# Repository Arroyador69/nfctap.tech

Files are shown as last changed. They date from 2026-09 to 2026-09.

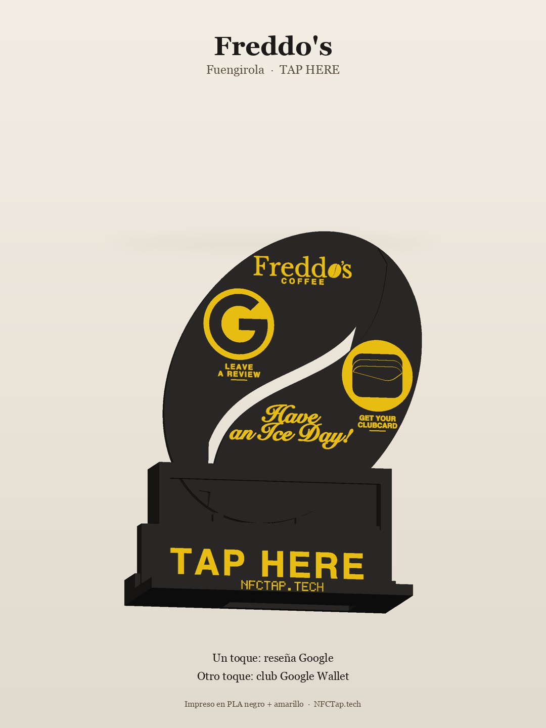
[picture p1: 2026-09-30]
disenos/stl/freddos-fuengirola/opcion-tap/whatsapp/Freddos-NFC-propuesta.jpg

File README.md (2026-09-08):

# NFCTap.tech — tarjetas NFC de reseñas Google

Marca: **nfctap.tech** (canónico). `nfctab.tech` redirige aquí hasta que deje de renovarse. Web en `web/` (Next.js, Vercel). App de programación NFC en `nfctap-config/` (**NFCTap Config**). Diseños 3D en `disenos/`.

```bash
cd web && npm install && npm run dev
```

- Tienda: http://localhost:3000
- Personalizar + pagar: http://localhost:3000/personalizar
- Dashboard: http://localhost:3000/dashboard (clave `nfctab` hasta que pongas `DASHBOARD_PASSWORD`)

Deploy Vercel: root directory = `web`. Polar se conecta después (env en `web/.env.example`).

Cada push a GitHub lanza **Actions → CI** (lint + build de `web/`).

### De un pedido al STL

1. Cliente (o tú en `/dashboard/nuevo`) diseña y guarda.
2. En el pedido: **Descargar ZIP para Orca** (STL + colores + pausa NFC + URL).
3. Orca-Flashforge → importar 01–05 → ensamblar → color por pieza → pausa → imprimir.
4. Local, si quieres regenerar: `python3 disenos/generar_tarjetas.py --pedido pedido.json`

En Vercel, crea un Blob Store y pon `BLOB_READ_WRITE_TOKEN` para que los pedidos no se pierdan.

---

# Impresora Flashforge AD5X

Proyecto listo para cuando llegue la impresora: diseños STL, cómo meter la tira NFC a media impresión y cómo programarla para que el móvil abra la reseña de Google.

---

## Respuesta rápida

**¿Puedes poner cualquier color?** Sí. Compras el filamento del color que quieras (hay cientos: negro, blanco, oro, rojo marca del cliente, silk, mate…). La AD5X no limita el color. Lo que limita es **cuántos colores caben a la vez**: el IFS lleva **4 bobinas**. En una sola tarjeta puedes combinar hasta 4 colores. Entre un pedido y otro cambias bobinas y usas los que quieras.

**¿Hay repos y plantillas?** Sí. Abajo tienes los que valen y, además, **ya tienes las primeras tarjetas generadas en este proyecto** (no dependes de Cults de pago).

**Flujo completo:** diseñar → rebanar en Orca-Flashforge → pausar en la capa del hueco → meter la pegatina NFC Ø25 mm → terminar impresión → escribir la URL de Google con NFC Tools o NFCTap Config.

---

## 1. Tu impresora: Flashforge Adventurer 5X (AD5X)

Comprada el 3 sep 2026, [Amazon B0DMWCWZXL](https://www.amazon.es/dp/B0DMWCWZXL), ~349 €. Nº1 en impresoras 3D en Amazon.es.

| Dato | Valor real |
| --- | --- |
| Volumen | 220 × 220 × 220 mm |
| Velocidad | hasta 600 mm/s (impresión típica ~300 mm/s) |
| Aceleración | 20 000 mm/s² |
| Estructura | CoreXY metálica |
| Boquilla | 0,4 mm de serie (0,25 / 0,6 / 0,8 opcionales), hasta 300 °C |
| Cama | PEI magnética, hasta 110 °C |
| Colores a la vez | **4** con IFS (Intelligent Filament System) |
| Recarga auto | sí, hasta 4 kg / 4 canales del mismo color |
| Materiales | PLA, HS PLA, mate, silk, PETG, ASA, TPU, PLA-CF, PETG-CF |
| Software | **Orca-Flashforge** (recomendado) o Orca Slicer |
| Conexión | Wi-Fi, USB, Ethernet |
| App / granja | Flash Maker |

Para estas tarjetas usa **PLA mate** (o HS PLA). Queda más “producto” y no brilla de forma barata. **No uses filamento con fibra de carbono ni metal** cerca del NFC: atenúa o mata la señal.

Docs oficiales útiles:

- [Impresión multicolor AD5X](https://www.flashforge.com/a/docs/ad5x/multi-color-printing)
- [Enviar a imprimir desde Orca-Flashforge](https://www.flashforge.com/a/docs/ad5x/print-via-orca-flashforge)
- [Producto AD5X](https://www.flashforge.com/products/flashforge-ad5x-3d-printer)

En la cama de 220 mm caben **2 atriles genéricos** a tamaño real. Una sola pausa (capa 24) sirve para las dos pegatinas.

---

## 2. Cómo se diseñan (y qué hay ya hecho)

Una tarjeta de reseña no es un solo bloque. Son **piezas de color** + un **hueco interno** para el NFC:

```
   [estrellas oro]  [texto blanco]  [icono]
  -----------------------------------------
 |              CUERPO (negro/color marca)  |
 |           ┌─────────────────┐            |
 |           │  NFC Ø25 mm     │  ← hueco   |
 |           └─────────────────┘            |
  -----------------------------------------
```

### Lo que ya tienes en esta carpeta

```
disenos/
  generar_generica.py              ← atril 15 € (G + estrellas), 3 colorways + placa ×2
  generar_tarjetas.py              ← geometría + cartera / pedidos a medida
  stl/
    generica-negra-amarillo/       ← la de 15 € que más se imprime
    generica-blanca-negra/
    generica-negra-roja/
    opciones/v4-flotante/          ← la genérica: estrellas + G + TAP
    freddos-fuengirola/            ← encargo cliente (no serigrafía)
    alberto-cartera/               ← cartera slim, 2 NFC (WA + web)
```

Cada genérica incluye:

| Archivo | Color | Qué es |
| --- | --- | --- |
| `01_cuerpo.stl` | Negro o blanco | Placa + pie + hueco NFC |
| `02_acento.stl` | Amarillo / negro / rojo | Estrellas + G + TAP + NFCTAP.TECH |
| `01_cuerpo_a.stl` + `01_cuerpo_b.stl` | igual | Dos piezas sueltas (no pegadas) |
| `02_acento_a.stl` + `02_acento_b.stl` | igual | Acento de cada una, mismo sitio |
| `PAUSA_NFC.txt` | — | Capa 24 (4,80 mm) |

**Prueba de impresión (Google review):** Flash Studio → Importar `01_cuerpo.stl` + `02_acento.stl` de `generica-negra-amarillo/` (una). Para dos: `*_a` y `*_b` (cuatro STL, dos grupos). **Agrupar, no Reparar.** Pausa **capa 24**. Pegatina Timeskey Ø25 hundida, adhesivo a la cama.

### Regenerar genéricas

```bash
python3 disenos/generar_generica.py
```

### Personalizar un cliente (cartera / pedido plano)

```bash
python3 disenos/generar_tarjetas.py \
  --nombre "bar-pepe" \
  --linea1 "BAR PEPE" \
  --linea2 "RESEÑA" \
  --nfc moneda_25
```

Stock NFC (los primeros 50): [Timeskey NTAG215 Ø25 mm](https://www.amazon.es/dp/B08LD99GZT). El hueco por defecto es `moneda_25` (Ø 28 + 0,4 mm de holgura → **~Ø 28,4 × 0,8 mm**), para meterla a mano sin que roce.

| Preset | Hueco | Para qué |
| --- | --- | --- |
| **`moneda_25`** | Ø 28 × 0,8 mm | **Pegatinas Timeskey Ø25 mm (el stock)** |
| `moneda_30` | Ø 31,5 × 1,0 mm | Monedas grandes |
| `tira_45x15` | 47 × 17 × 0,8 mm | Tiras adhesivas (si compras otras) |
| `tira_40x20` | 42 × 22 × 0,8 mm | Tiras más anchas |
| `tira_35x15` | 37 × 17 × 0,8 mm | Tiras cortas |

Si una pegatina concreta roza, sube `d` en `PRESETS_NFC` de `generar_tarjetas.py`. El hueco debe quedar **~1,5 mm más grande por lado** que el chip.

### En Orca-Flashforge (cuando llegue la máquina)

1. Instala [Orca-Flashforge](https://www.flashforge.com) y elige impresora **AD5X**.
2. Añade hasta 4 filamentos en la barra izquierda (IFS = máx. 4).
3. Importa `01_cuerpo.stl`, `02_estrellas.stl`, `03_texto.stl`, `04_icono.stl`.
4. Si no coinciden, selecciónalos todos → clic derecho → **Ensamblar** (o alinea origen).
5. En el panel Objetos, asigna un color/filamento a cada pieza.
6. Opcional: **Añadir texto** para el nombre del negocio (relieve 0,4 mm).
7. Rebana. En **Vista previa**, slider derecho → capa de `PAUSA_NFC.txt` → clic derecho → **Añadir pausa**.
8. Activa **Enable IFS**, mapea canales (negro→canal X, etc.) y envía.

Ajustes que funcionan bien en tarjetas:

- Capa 0,20 mm (si quieres más detalle en texto: 0,16 mm y recalcula la capa de pausa)
- 3 perímetros, relleno 15–20 % gyroid
- Primera capa lenta, cama PEI limpia
- Generador de paredes **Arachne** para el texto
- PLA ~210/60 °C (sigue el carrete)

---

## 3. Repos, plantillas y sitios (investigado)

No hay un “GitHub oficial de tarjetas Google”. El nicho está en modelos 3D + apps NFC. Esto es lo que sí existe y sirve:

### Código / generadores (gratis)

| Recurso | Para qué |
| --- | --- |
| [nfc-keychain-generator-blender-addon](https://github.com/Clonephaze/nfc-keychain-generator-blender-addon) | Addon de Blender: tarjetas, llaveros, hueco NFC, SVG, QR |
| [Dog tag paramétrico RFID (Printables + OpenSCAD)](https://www.printables.com/model/438828-universal-parametric-rfid-compatible-dog-tag-gener) | Generador OpenSCAD con hueco RFID/NFC |
| **Este repo (`generar_tarjetas.py` + `.scad`)** | Plantilla propia, lista para AD5X y tus tiras |

### Modelos listos para descargar

| Recurso | Notas |
| --- | --- |
| [MakerWorld — Minimalist Google Review NFC & QR](https://makerworld.com/en/models/1469384-minimalist-google-review-nfc-qr-code) | Soporte de mesa + QR (el QR hay que generarlo tú) |
| [MakerWorld — NFC stand con chip embebido](https://makerworld.com/en/models/2370320-nfc-customizable-stand-embedded-chip) | Pausa ya puesta, chip 25 mm |
| [MakerWorld — QR sign paramétrico + NFC](https://makerworld.com/en/models/2401859-customizable-qr-code-sign-nfc-frame-optional) | Muy configurable |
| [Printables — soporte NFC de mostrador](https://www.printables.com/model/1186851-curved-tabletop-nfc-tag-holder) | Atril, se inserta el tag a media impresión |
| [Cults — Smart NFC Review Card](https://cults3d.com/tr/3d-model/ev/smart-nfc-review-card-boost-your-business) | De pago; 85,6×54×3 mm, pausa en capa 10 |

### Programar el NFC (apps)

- [NFC Tools](https://www.wakdev.com/en/apps/nfc-tools.html) — iOS y Android (la que usarás)
- NFC TagWriter (NXP) — alternativa Android
- [Guía de escritura de tarjetas NFC para reseñas](https://upwardbound.media/resources/nfc-card-programming)

Slicer y pausa: [cómo añadir pausa en OrcaSlicer](https://printago.io/guides/orca-slicer-pause-at-layer) (Orca-Flashforge es el mismo motor).

---

## 4. Meter la pegatina NFC a media impresión

1. La impresora hace el pozo Ø28 y el asiento Ø26 (anillo de acento = mira).
2. **Pausa** en la primera capa que taparía el hueco (genérica: **4,80 mm / capa 24**).
3. Colocas la pegatina Timeskey **Ø25 mm hundida y centrada**, adhesivo hacia la cama, sin que sobresalga.
4. Reanudas. La impresora sella el NFC dentro. Queda invisible y protegido. Si sobresale, no reanudes (montañita).

Consejos que evitan fallos:

- El nozzle está caliente: no toques la cama; usa pinzas si hace falta.
- Estas pegatinas son finas (~0,2 mm). El pozo tiene 1,6 mm de alto: caben holgadas.
- No las pongas arrugadas: el cabezal las puede arrancar.
- Programa el NFC **después** (atraviesa el PLA sin problema) o **antes** si quieres probar el chip. Después es más cómodo.
- iPhone lee NFC de serie; Android también (NFC activado).
- No van sobre metal. No las pases a solo lectura hasta comprobar el enlace.

---

## 5. Programar el NFC para Google Reviews

Necesitas el **enlace directo a escribir reseña**, no el Maps genérico.

### Conseguir el enlace (elige uno)

**A. Desde el perfil de empresa (más fácil)**  
[Google Business Profile](https://business.google.com) → el negocio → **Pedir reseñas** / Ask for reviews → copiar el enlace corto:

`https://g.page/r/XXXXXXXX/review`

**B. Con Place ID**  
1. Abre el [Place ID Finder de Google](https://developers.google.com/maps/documentation/javascript/examples/places-placeid-finder).  
2. Busca el negocio, copia el `place_id` (empieza por `ChIJ…`).  
3. Monta:

`https://search.google.com/local/writereview?placeid=AQUI_EL_PLACE_ID`

Ese enlace abre **directamente el formulario de reseña**.

### Escribirlo en el chip

1. Instala **NFC Tools** en el móvil.
2. Write / Escribir → Add a record → **URL / URI**.
3. Pega el enlace de reseña.
4. Write → acerca el móvil a la tarjeta (por la cara, 1–2 cm).
5. Prueba con **otro** móvil: debe abrir Google y la reseña, sin app extra.
6. Cuando esté bien, en NFC Tools puedes **bloquear** el tag (write-protect) para que el cliente no lo pisen. Bloquea solo al entregar.

Chips que funcionan (NTAG de NXP, los que entiende iPhone y Android):

| Chip | Memoria | Recomendado |
| --- | --- | --- |
| NTAG213 | ~180 B | Vale para una URL corta |
| **NTAG215** | ~504 B | **El que debes comprar** |
| NTAG216 | ~888 B | Sobra para esto |

Las Timeskey B08LD99GZT son **NTAG215**. Si al escribir falla por “poca memoria”, acorta la URL (usa el `g.page`).

---

## 6. Lista de la compra para el día 1

Ya tienes la impresora. Falta esto:

| Qué | Para qué | Nota |
| --- | --- | --- |
| PLA mate negro 1 kg | Cuerpo | El 80 % de los pedidos |
| PLA blanco 1 kg | Texto / icono | Contraste |
| PLA oro / amarillo silk | Estrellas | Aspecto “5 estrellas” |
| 1 color extra (rojo, azul, verde) | Marca del cliente | El 4º canal del IFS |
| Pegatinas NFC **NTAG215 Ø25 mm** | El chip | [Timeskey B08LD99GZT](https://www.amazon.es/dp/B08LD99GZT); si compras más, mismas Ø25 |
| Alcohol isopropílico | Limpiar PEI | Primera capa limpia |
| Orca-Flashforge | Slicer | Gratis, web Flashforge |
| NFC Tools | Programar | Gratis en App Store / Play |

Opcional más adelante: PLA de colores de marca (corporativos), PETG si van a terraza al sol, más AD5X cuando escales (la propia Flashforge las vende como granja).

---

## 7. Coste y producto (para el negocio)

Números de la genérica 15 € (ver `COSTE.txt` en cada carpeta):

- PLA ~47 g → **~1,04 €**
- NFC NTAG215 Ø25 → **~0,45 €**
- Luz + fallos → **~0,47 €**
- Coste ~**1,96 €**/ud · venta **15 €** · margen ~13 €
- En cama caben **2** a tamaño real (`*_a.stl` + `*_b.stl`, sueltas)

No uses el **logotipo oficial de Google** (la G de 4 colores) en producto a la venta sin permiso de marca. “Reseña en Google”, estrellas y un icono genérico es lo correcto y es lo que generan estos STL.

---

## 8. Plan de las próximas semanas

1. **Hoy:** imprimir `generica-negra-amarillo` (o `*_a` + `*_b` para dos sueltas). Pausa capa 24. G + estrellas.
2. **Stock:** negra+amarillo, blanca+negra, negra+roja. Misma geometría.
3. **Pedido web:** `/personalizar?kind=generica` → ZIP / `generar_generica.py`.
4. **Personalizada 30 €:** mismo atril, logo + textos.

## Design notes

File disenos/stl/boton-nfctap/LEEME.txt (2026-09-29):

Botón NFCTap — marca (NFC / Tap / .Tech)
========================================

Mismo tamaño que la lista nevera: Ø38 × 2.0 mm.
Cara: NFC arriba, Tap, .Tech (con el punto). Aro amarillo.
NFC Timeskey Ø25 en el centro. Pausa a mitad.

  01_cuerpo.stl   negro
  02_acento.stl   blanco  (letras + mira NFC)
  03_aro.stl      amarillo (aro exterior)

Agrupar las 3. NO Reparar.

Uso
---
Pegar en el cajón de filamento / taller. Programar el chip
con NFCTap Config → URL https://nfctap.tech/taller/casa
(misma clave que la lista nevera; solo Wi‑Fi de casa).

Imprime
-------
Pausa OBLIGATORIA capa 7 (1.40 mm). Ver PAUSA_NFC.txt.
Pozo Ø28, asiento Ø26, pegatina Ø25.
REVERSO en la cama. Pegar ese lado (cinta 3M).

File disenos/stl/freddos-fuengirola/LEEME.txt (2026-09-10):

Freddo's Fuengirola — grano NFC + cuna-letras
=============================================

Que es
------
1. GRANO rugby inclinado, S HUECA como el logo (se ve el aire).
   Los lóbulos son UNA pieza: carne en las puntas + enlace oculto en el nido.
   Disco amarillo + TAP negro. Dos NFC Ø25. Abajo: tetones.
2. CUNA = placa negra + Freddo's ENTERO en amarillo (04). El nido va
   8 mm POR ENCIMA del wordmark. El pie delantero queda BAJO las letras,
   no las tapa. Grano de arriba:
   ranura 8,8 mm, labio 8,5 mm, nido 34 mm, agujeros de los tetones.
3. Firma en el pie, debajo de Freddo's: NFCTAP.TECH

Montaje
-------
        [        GRANO (de lado)        ]
        [   tetones → agujeros del nido ]
        [   ranura en lo alto de Freddo's ]
        [  F r e d d o ' s              ]
        [  NFCTAP.TECH                  ]
        [=========== pie 72 mm =========]

Imprime
-------
ANTES de las 8 h: test-encaje/ (stub + cuna sin letras). Prueba el tap.

GRANO: solo 01 + 02. Agrupar. Pausa capa 24. NO Reparar.
CUNA:  solo 03 + 04. Agrupar. Negro=03, amarillo=04. Sin pausa.
       NO mezclar el grano en la misma cama.
       Coloca la cuna APOYADA EN LA ESPALDA (la cara plana trasera
       en la cama). Amarillo = último, la cara de Freddo's arriba.
       Sin soportes. Si avisa de regiones flotantes, está mal girada.

Al acabar: cuna DE PIE. Grano de canto, de ARRIBA, tetones primero. Clac.
Los agujeros del nido abren HACIA ARRIBA (caen los tetones). De cara al
cliente no se ven: delante hay pared. Si FlashPrint avisa de contornos
con geometría incorrecta, NO imprimas — el STL está mal.

Pie
---
Fondo 72 mm. Hueco de lastre en el pie TRASERO (tuercas M8).
El estante delantero es bajo: no tapa Freddo's.
Se tapa el hueco con cinta 3M. Lastre + el stand pegado.
Sin cinta, un empujón alto vuelca cualquier PLA de 20 cm.

Colores: negro + amarillo. Los dos como PLA.

Medidas (80 % del original, NFC igual)
--------------------------------------
Alto montado sobre mesa: 205 mm
Letras Freddo's (hasta la ranura): 33 mm
Grano suelto: 143 × 161 × 8 mm
Pie: 159 mm de ancho × 72 mm de fondo
Nido 34 mm · ranura 8.8 mm (holgura 0.8) · labio 8.5 mm
Tetones: 3 × Ø5.8 / agujero Ø6.8 × 7 mm
NFC: pozo Ø36 · asiento Ø30 · pegatina Ø25 (no escala)

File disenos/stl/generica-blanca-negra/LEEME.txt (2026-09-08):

Atril genérico NFCTap — reseña Google (15 €)
============================================

Que es
------
Placa + pie integrado. Estrellas flotantes, G y TAP debajo.
NFC DENTRO, justo bajo la G (o el logo en personalizada). Pausa a mitad.
Antes de pausar se imprime un disco de acento en el suelo del pozo:
eso es la mira. La pegatina va ENCIMA de ese círculo.

  01_cuerpo.stl / 02_acento.stl     una pieza (agrupar, no Reparar)
  01_cuerpo_a/b.stl + 02_acento_a/b.stl   dos SUELTAS en la cama

Personalizada (30 €): el MISMO cuerpo. Logo en acento en vez de la G.

Imprime
-------
Agrupar 01 + 02. NO Reparar el modelo.
Capa 0,20 mm, 3 perímetros, gyroid 15 %, Arachne.
Pausa OBLIGATORIA capa 24 (4.80 mm). Ver PAUSA_NFC.txt.
Pozo Ø28, asiento Ø26, pegatina Ø25.
Se imprime con la cara de la placa hacia arriba (el pie sale hacia Z).
Al acabar se pone de pie.

Colores de esta carpeta: cuerpo = blanco, acento = negro.

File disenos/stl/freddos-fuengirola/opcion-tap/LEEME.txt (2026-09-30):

Freddo's Fuengirola — OPCIÓN cuna TAP
=====================================

No sustituye a la cuna Freddo's de la carpeta padre. Es otra cara.

Qué cambia
----------
Misma cuna negra (ranura, nido, pie, tetones, tamaños).
El grano es el de siempre (Freddo's COFFEE, reseña, clubcard).
En la placa, en vez de repetir Freddo's:

        TAP HERE

Solo inglés, un tamaño que llena la cara (sin español). Vale para los dos chips:
  IZQ  G Google → reseña
  DER  Wallet   → clubcard / ticks del café

Imprime
-------
GRANO: 01 + 02 de la carpeta padre (no hace falta reimprimirlo).
CUNA:  03 + 04 DE ESTA carpeta. Agrupar. Negro=03, amarillo=04.
       Espalda plana en la cama. Sin pausa. Sin soportes.

03 es la misma pieza negra que la cuna Freddo's (copia).
04 es nuevo: TAP HERE + NFCTAP.TECH en el pie.

Medidas (igual que la cuna Freddo's)
------------------------------------
Alto montado: 205 mm
Pie: 145 × 72 mm
Nido 34 mm · ranura 8.8 mm · labio 8.5 mm
Cara: TAP HERE 14.0 mm (solo inglés)

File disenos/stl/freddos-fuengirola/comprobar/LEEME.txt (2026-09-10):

NO IMPRIMIR este STL.
Es el grano YA metido en la cuna, para verlo en FlashPrint.
Si se ve el óvalo encajado de canto, tetones en el suelo del nido, OK.
Lee ENCAJE.txt (mismas cifras del grano y de la cuna).
Para fabricar: 01+02 (grano) y 03+04 (cuna), en dos camas.

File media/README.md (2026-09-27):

# NFCTap · media

Reels solo con **tus grabaciones**. Carrusel solo con **tus fotos**. Subtítulos amarillos. Voces Azure España (Ximena / Tristan).

Cada Reel: **pieza acabada** (hook) → **proceso de impresión** (cuerpo) → **nfctap.tech en uso** (cierre). El cierre dice «Lo podrás encontrar en la web. Envíos a toda España.» con subtítulos amarillos.

## Dónde pegar el material

```
media/assets/bank/resultado/   1 MOV nuevo de pieza acabada → hook
media/assets/bank/proceso/     2 MOV nuevos de impresión / NFC / TAP → cuerpo
media/assets/bank/web/         1 MOV LARGO de nfctap.tech → cierre (trozos distintos)
media/assets/bank/imagenes/    3 fotos JPG/PNG → único carrusel del pack
```

Cualquier MOV/MP4 vale para los Reels. El sistema los deja a 1080×1920 sin recortar.

El cierre de la web **no** corta siempre el mismo segundo: recorre el vídeo largo
a trozos. En la suma de Reels se ve casi entero.

Para el carrusel: al menos 3 fotos. Si pones exactamente 3, salen en orden de nombre (`01.jpg`, `02.jpg`, `03.jpg`). Si el iPhone guarda HEIC, exporta a JPG.

## Pack del día

Dos Reels (voz de mujer + voz de hombre) + **un** carrusel de 3 fotos + stories.

Los dos Reels **no abren con el mismo clip**. Si el de María usa `IMG_0562`, el de Andrés usa otro de `resultado/`.

```bash
cd media
source .venv/bin/activate
python -m nfctap_media doctor
python -m nfctap_media day
python -m nfctap_media open
```

Aún no publica solo. Polar después.

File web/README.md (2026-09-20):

# NFCTap.tech — web

Tienda + personalizador + dashboard de pedidos. Next.js 16, lista para Vercel.

## Local

```bash
cd web
cp .env.example .env.local
npm install
npm run dev
```

- Tienda: http://localhost:3000
- Personalizar: http://localhost:3000/personalizar
- Dashboard: http://localhost:3000/dashboard · clave por defecto `nfctab`

## Precios (no son 2×1 con cupón)

| Producto | Polar | Precio |
|---|---|---|
| Google / WhatsApp / Instagram × 1 | `POLAR_PRODUCT_GENERIC_1` | 20 € |
| Pack × 2 (también una de cada) | `POLAR_PRODUCT_GENERIC_2` | 35 € (no 40 €) |
| Con logo × 1 | `POLAR_PRODUCT_CUSTOM_1` | 30 € |
| Con logo × 2 | `POLAR_PRODUCT_CUSTOM_2` | 55 € (no 60 €) |
| TAP Wi‑Fi pared × 1+ | `POLAR_PRODUCT_WIFI_1` | 15 € cada una |

La pieza única (70 €) no se vende en Polar: se cierra por email.

En el checkout Polar cobra **producto + envío** (ad-hoc). Península gratis desde 45 € de producto.

## Polar

En [polar.sh](https://polar.sh) (organización NFCTap, **producción**, no sandbox):

1. Settings → Organization Access Token con `products:write`, `checkouts:write` y `checkouts:read`.
2. Settings → Webhooks → endpoint `https://nfctap.tech/api/webhook/polar` (formato Raw). Eventos: `checkout.updated`, `order.created`, `order.paid`. Copia el secret `whsec_…`.
3. Crea los productos (atriles + TAP Wi‑Fi):

```bash
cd web
POLAR_ACCESS_TOKEN=polar_oat_… POLAR_SERVER=production npm run polar:setup
```

El script escribe los IDs en `.env.local`. Pégalos también en Vercel.

4. En Vercel: `POLAR_ACCESS_TOKEN`, `POLAR_WEBHOOK_SECRET`, `POLAR_SERVER=production` y los `POLAR_PRODUCT_*` (incl. `POLAR_PRODUCT_WIFI_1`).

**Bizum** no se activa a mano. Polar lo muestra en el checkout cuando el comprador está en España (EUR, pago único). La web le pasa la IP y el país ES. El cliente confirma en su banco; Polar cobra, envía el recibo y avisa a la web por webhook. No uses Bizum al número de teléfono de la tienda: eso es entre particulares, no hay confirmación automática del pedido.

## Vercel

1. Importa el repo. **Root Directory:** `web`
2. Variables: `DASHBOARD_PASSWORD`, `DASHBOARD_SECRET`
3. Blob: `BLOB_READ_WRITE_TOKEN` (Storage → Blob)
4. Polar (producción): ver arriba

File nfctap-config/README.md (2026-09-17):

# NFCTap Config

App para **programar pegatinas NFC** de NFCTap (`nfctap.tech`). Nombre: **NFCTap Config**. Bundle ID `tech.nfctab.config` (no cambiar: ya está en App Store Connect). «NFC Tap» está pillado en la App Store (ST).

Hoy: **gratis, para ti**. Paywall más adelante.

## Qué graba (NDEF)

Negocio: reseña Google, web, PDF/menú, WhatsApp (prefijo + número + mensaje), app, TripAdvisor, reservas, PayPal.

Redes: Instagram, TikTok, Facebook, Telegram, Maps, YouTube, LinkedIn, X, Spotify.

Contacto: llamada, email, SMS, vCard.

Conexión: **Wi‑Fi con contraseña**. El iPhone **no se une solo** al Wi‑Fi por NFC (Apple no lo permite). Se graba una URL `nfctap.tech/w#…` que abre nombre y clave para copiar, más el registro WSC para que Android a menudo se una solo.

Extra: texto, GPS, URI libre.

El cliente **no instala esta app**. Toca y el sistema abre el enlace.

Se puede programar **cualquier chip NDEF** (NTAG213/215/216, Ultralight…). No: bancarias, bloqueadas, ni MIFARE Classic raras en iPhone.

El chip **no guarda un PDF**: guarda la URL. Las 200 “tareas” de NFC Tools (silencio, brillo…) automatizan **tu** Android y piden su app extra; aquí no, porque el cliente de la barra no las tiene.

## Cómo la ves ya (Expo Go)

```bash
cd nfctap-config
npm start
```

QR con Expo Go: ves pantallas y plantillas. **Expo Go no escribe NFC.**

## Cómo programas de verdad (hoy, Android)

1. Móvil Android con NFC + cable USB.
2. En el Mac:

```bash
cd nfctap-config
npx expo run:android
```

3. Configurar → Reseña Google → pega el enlace de Maps o del perfil de empresa → Buscar enlace. Te da el de reseña.

iPhone: Xcode (Archive para TestFlight). El fallo `impresora: No such file` es el espacio en la carpeta. El plugin `with-quoted-constants-script` y `scripts/bundle-rn-ios.sh` citan las rutas.

```bash
./abrir-xcode.sh
```

Hace falta el capability **NFC Tag Reading**. iPhone 7+.

## Cómo ganan las otras (para el paywall)

| App | Modelo |
| --- | --- |
| NFC Tools | Gratis + Pro ~4 € o IAP. Tareas/automatización en Pro. |
| NFC Tools Pro | App de pago. Perfiles, emular tag, 200 tareas. |
| Smart NFC y clones | Escritura básica gratis, ilimitado / plantillas de pago o suscripción. |

Para NFCTap, el dinero está en **la tarjeta física**. La app puede quedarse gratis para ti y, luego, un Pro (historial en la nube, lotes, varios operarios) si la usáis más gente.

## No hacemos (a propósito)

- Bloquear el chip (write-protect): irreversible en NTAG.
- Clonar pagos / bank cards.
- Automatizar el teléfono del cliente (eso es NFC Tasks, otro rollo).

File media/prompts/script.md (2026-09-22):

Eres el guionista de Reels de NFCTap (nfctap.tech). Hablas a dueños de bares, cafeterías y restaurantes en España.

El vídeo que verán es SIEMPRE material real de Alberto:
- Primeros segundos (hook): la pieza ACABADA en la barra.
- Cuerpo: el PROCESO (impresión, pausa NFC, TAP, logo).
- Cierre: la web nfctap.tech en uso (encargar, 3D, precios). Locutado fijo: «Lo podrás encontrar en la web. Envíos a toda España.»
- El cuerpo no nombra la web ni el envío: eso va solo en el cierre.

Productos (di el que toque, no solo Google):
- Google: se abre la reseña.
- WhatsApp: se abre el chat.
- Instagram: se abre el perfil.
- Pack de dos: también una de cada. 20 € una, 35 € dos. Con logo 30 / 55 €.

Reglas:
- Español de España, tuteo, frases cortas, para decirlas en voz alta.
- 32 a 78 palabras entre hook y cuerpo. 15 a 30 segundos.
- Primer segundo: dolor concreto (se van sin reseña, QR sucio, Maps, anuncios, WhatsApp que no entra, Instagram que no siguen).
- Luego el atril, que lo fabricáis aquí, y el precio solo si está en product.yaml (20 / 35 / 30 / 55 / 70 €).
- El cuerpo termina en el producto. El cierre oral es siempre «Lo podrás encontrar en la web. Envíos a toda España.»
- No locutes la URL larga de /guia/… Eso va en el caption de YouTube/Instagram, no en la voz.
- Si el dolor es reseñas o Maps, el producto es el atril de Google. Si es WhatsApp o Instagram, ese modelo. Si es QR o papel, el atril de barra. Si es Wi‑Fi de pared, la placa de 15 €.
- No inventes partnership con Google, Meta ni WhatsApp. No digas “te lleno el local”.
- No uses nombres de clientes reales. Es una escena, no un testimonio falso.
- No emojis. No hashtags dentro del locutado.
- Si el dolor es Maps o reseñas, habla de Google. Si no, generaliza: WhatsApp, Instagram o Google.

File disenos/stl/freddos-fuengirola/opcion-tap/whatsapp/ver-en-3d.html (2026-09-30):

# Freddo's

Gira con el ratón o el dedo

Tap here: Google review · tap here: Google Wallet · NFCTap.tech

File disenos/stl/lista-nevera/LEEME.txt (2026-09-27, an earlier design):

Botón NFC nevera — lista de la compra
=====================================

Círculo Ø38 × 2.0 mm (fina).
Cara: lista minimalista blanca + aro amarillo en el borde.
NFC Timeskey Ø25 en el centro. Pausa a mitad.

  01_cuerpo.stl   negro
  02_acento.stl   blanco  (lista + mira NFC)
  03_aro.stl      amarillo (aro exterior)

Agrupar las 3. NO Reparar.

Imprime
-------
Pausa OBLIGATORIA capa 7 (1.40 mm). Ver PAUSA_NFC.txt.
Pozo Ø28, asiento Ø26, pegatina Ø25.
REVERSO en la cama. Pegar ese lado a la nevera (cinta 3M).

URL del chip: https://nfctap.tech/lista/casa
Privada: solo Wi‑Fi de casa. Ver NFC.txt.

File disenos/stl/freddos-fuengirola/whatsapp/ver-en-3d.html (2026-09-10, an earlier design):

# Freddo's

Gira con el ratón o el dedo

Un toque reseña Google · otro toque puntos · NFCTap.tech

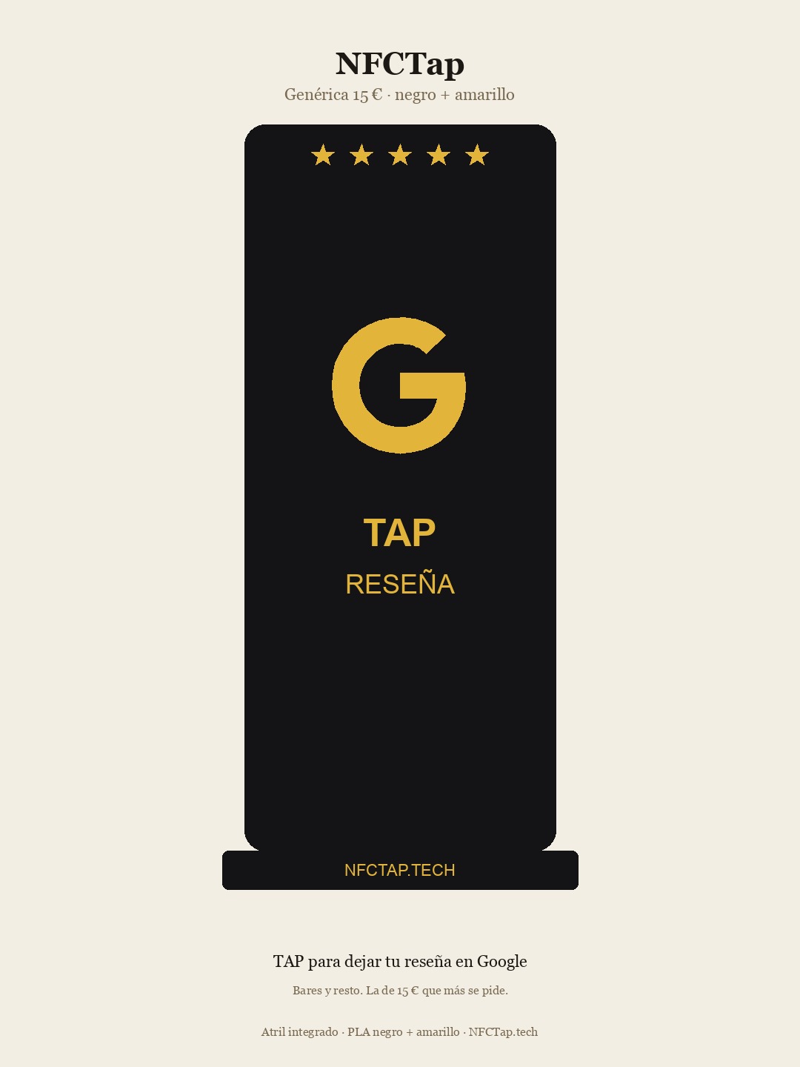
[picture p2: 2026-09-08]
disenos/stl/generica-negra-amarillo/propuesta.jpg

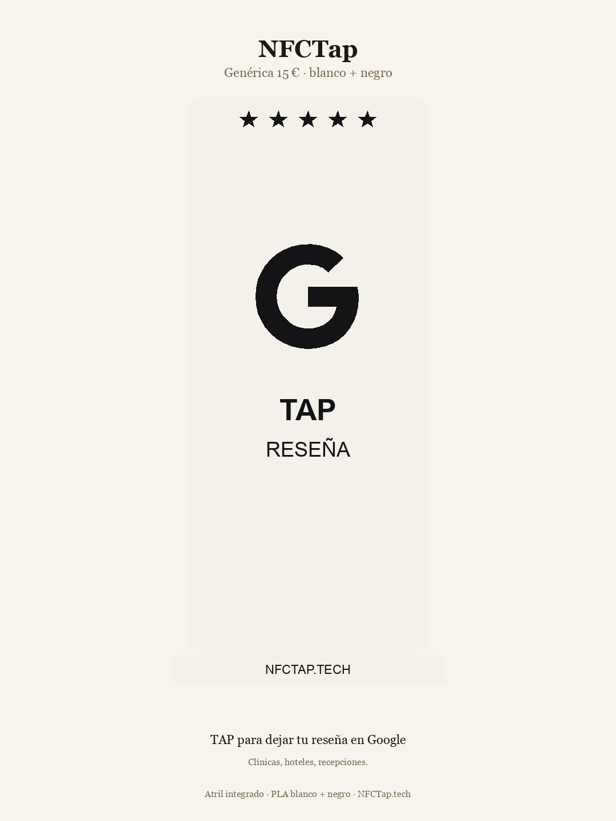
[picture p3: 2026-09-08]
disenos/stl/generica-blanca-negra/vista-previa.png

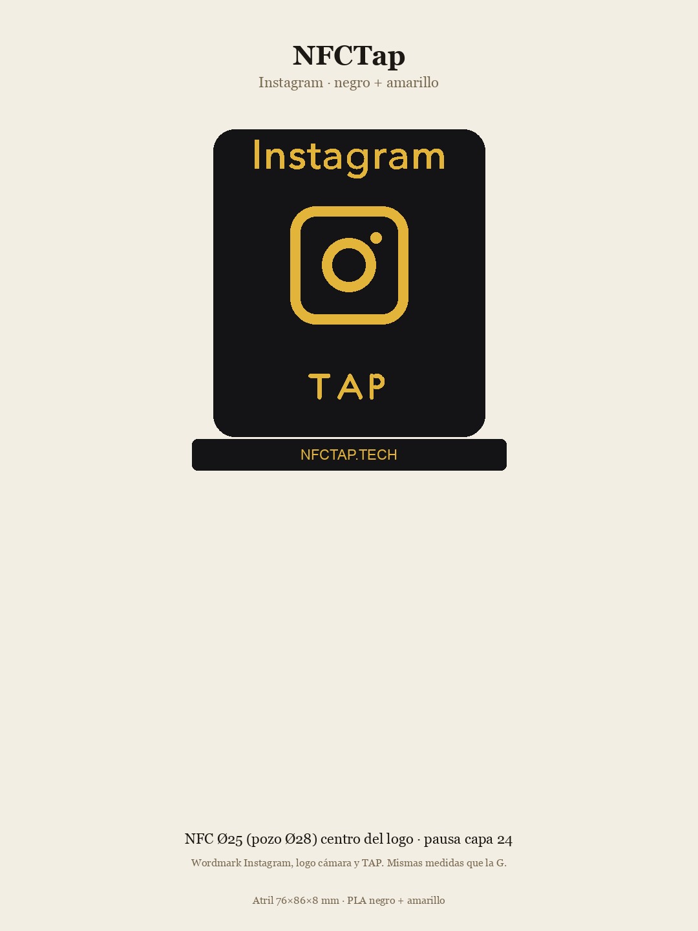
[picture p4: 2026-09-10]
disenos/stl/generica-instagram-negra-amarillo/propuesta.jpg

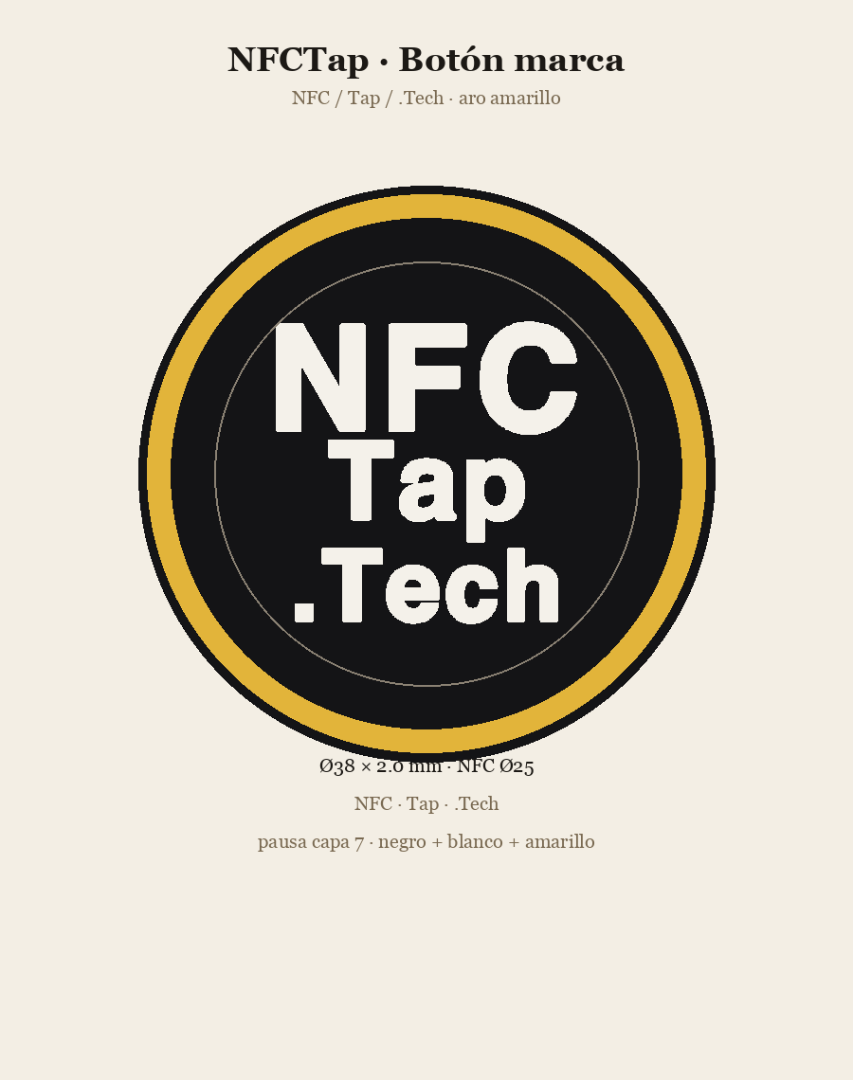
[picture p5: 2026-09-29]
disenos/stl/boton-nfctap/vista-previa.png

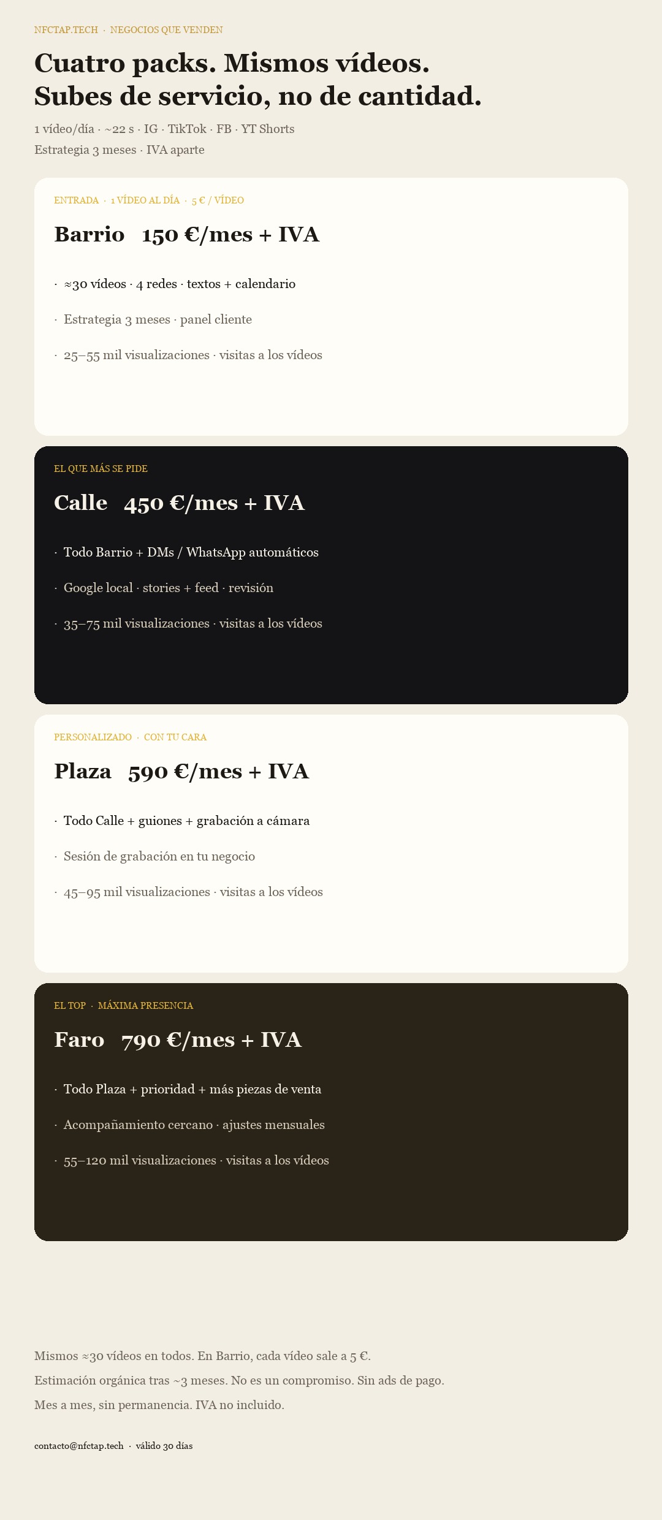
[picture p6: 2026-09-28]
comercial/redes/NFCTap-presupuesto-redes.jpg

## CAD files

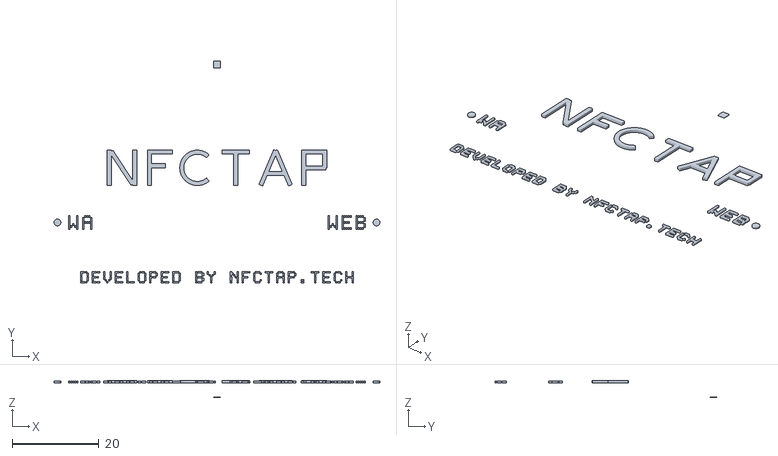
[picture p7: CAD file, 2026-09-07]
disenos/stl/alberto-cartera/02_oro.stl
75.2 x 51.1 x 4.00

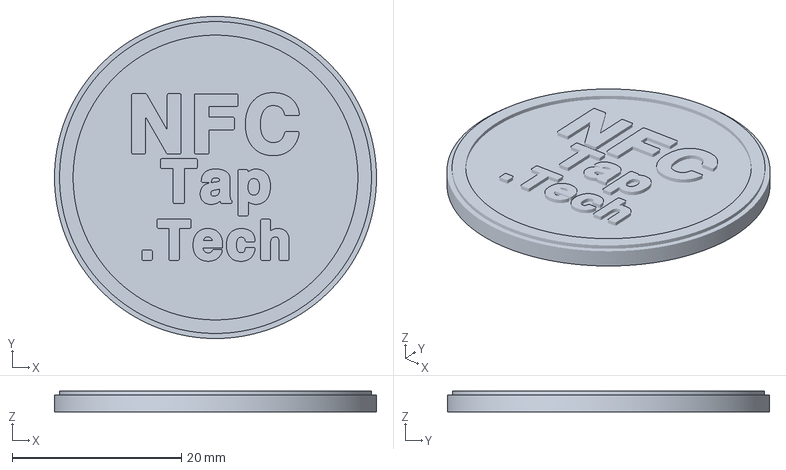
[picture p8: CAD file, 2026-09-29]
disenos/stl/boton-nfctap/boton nfctap.Tech.3mf
38.0 x 38.0 x 2.45 mm

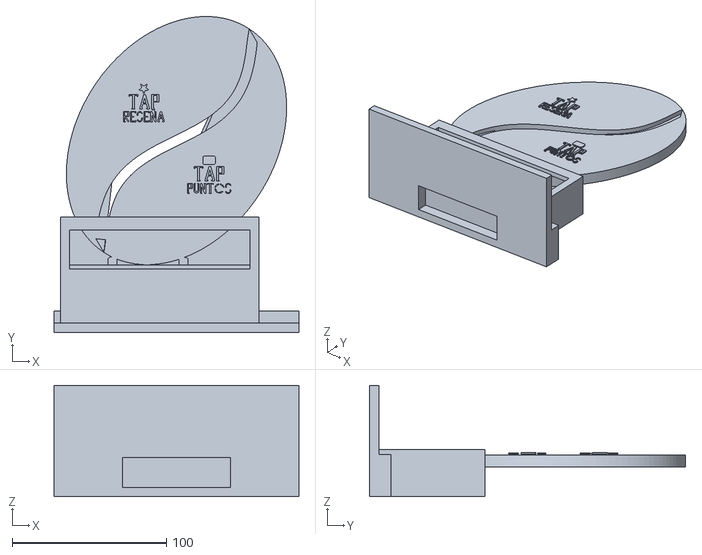
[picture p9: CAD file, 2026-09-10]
disenos/stl/freddos-fuengirola/comprobar/conjunto-NO-IMPRIMIR.stl
158.8 x 204.8 x 72.0

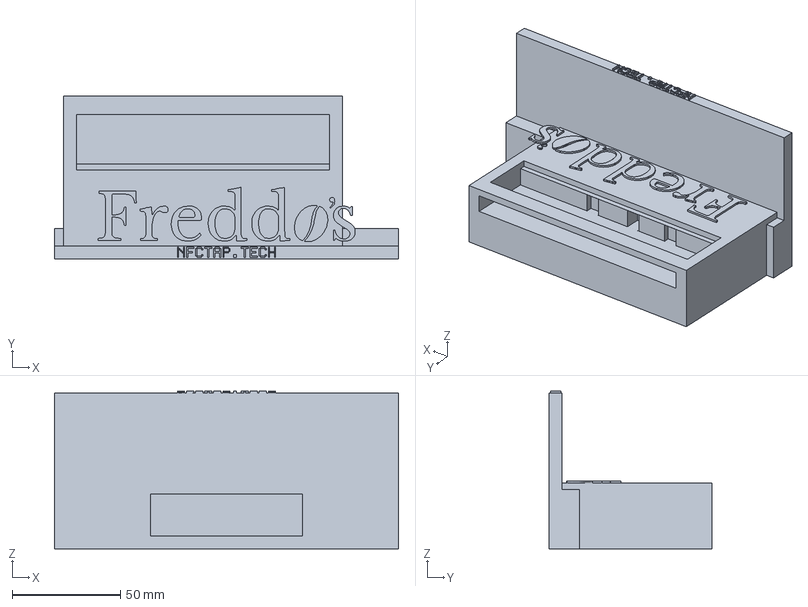
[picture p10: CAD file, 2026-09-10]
disenos/stl/freddos-fuengirola/cuna freddos.3mf
158.8 x 75.0 x 72.8 mm

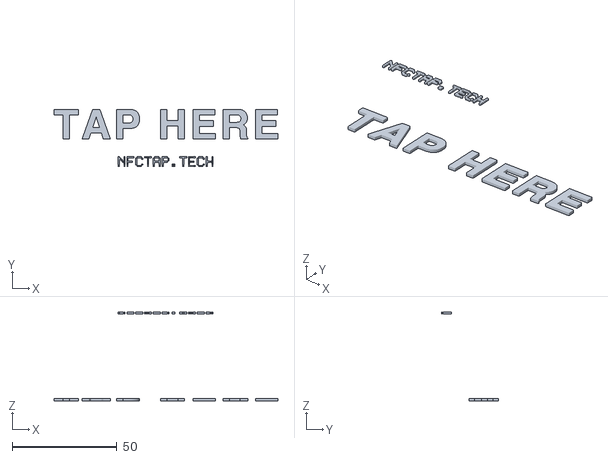
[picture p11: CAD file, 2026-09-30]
disenos/stl/freddos-fuengirola/opcion-tap/04_letras_oro.stl
106.9 x 27.4 x 42.4

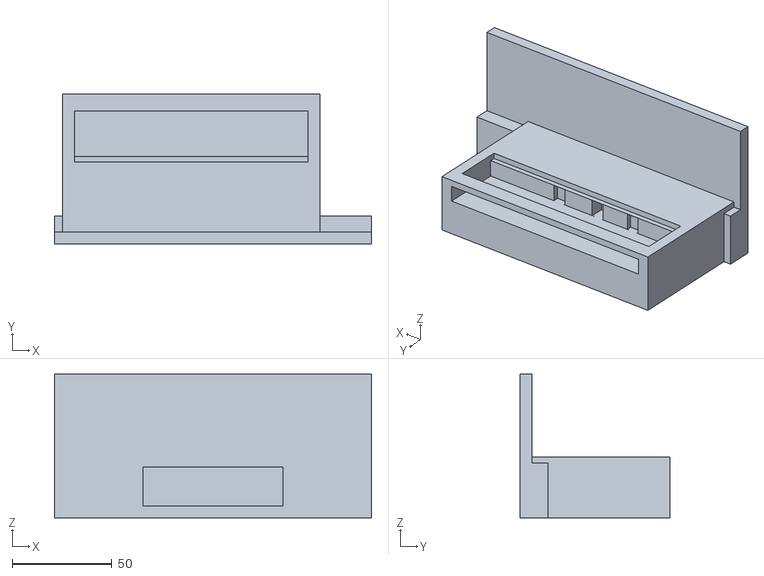
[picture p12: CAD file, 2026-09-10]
disenos/stl/freddos-fuengirola/test-encaje/02_cuna_nido.stl
158.8 x 75.0 x 72.0

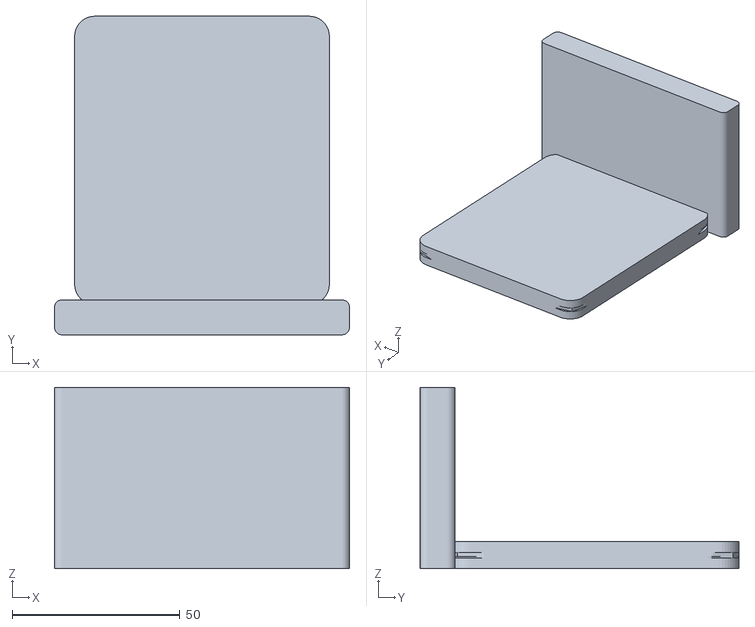
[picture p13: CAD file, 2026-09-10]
disenos/stl/generica-blanca-negra/01_cuerpo_a.stl
88.0 x 95.1 x 54.0

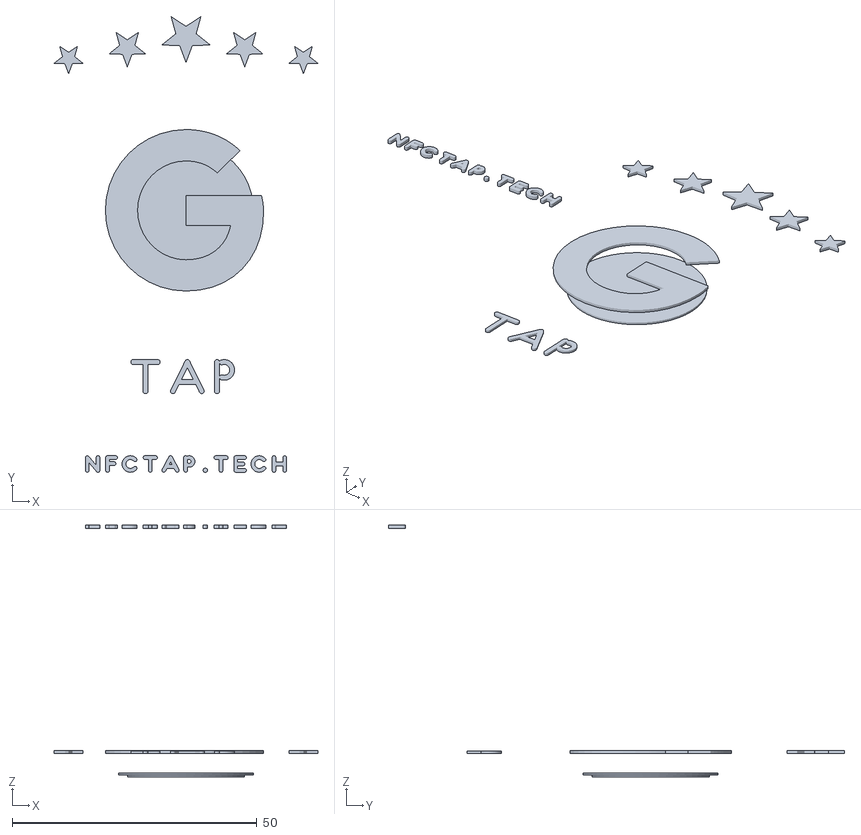
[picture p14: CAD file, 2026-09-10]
disenos/stl/generica-negra-amarillo/02_acento.stl
53.9 x 93.2 x 51.5

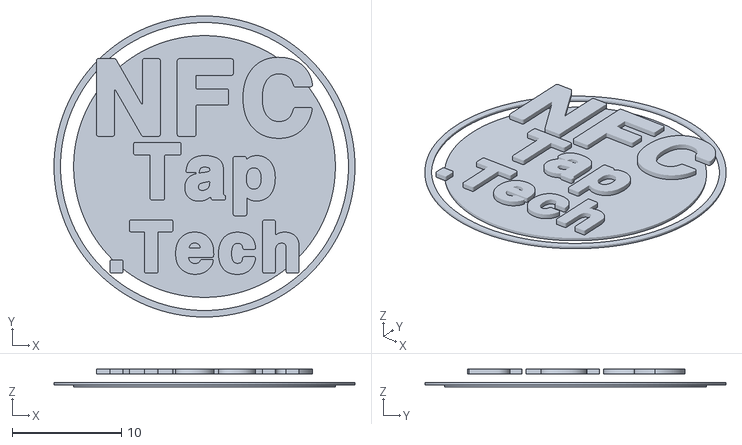
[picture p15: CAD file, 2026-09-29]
disenos/stl/boton-nfctap/02_acento.stl
27.6 x 27.6 x 1.65

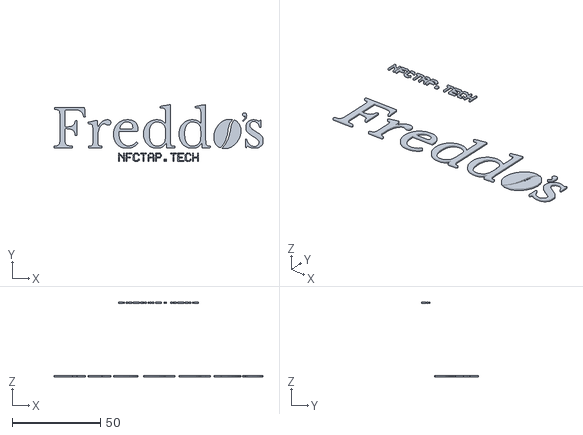
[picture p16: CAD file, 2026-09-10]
disenos/stl/freddos-fuengirola/04_letras_oro.stl
118.4 x 32.4 x 42.4

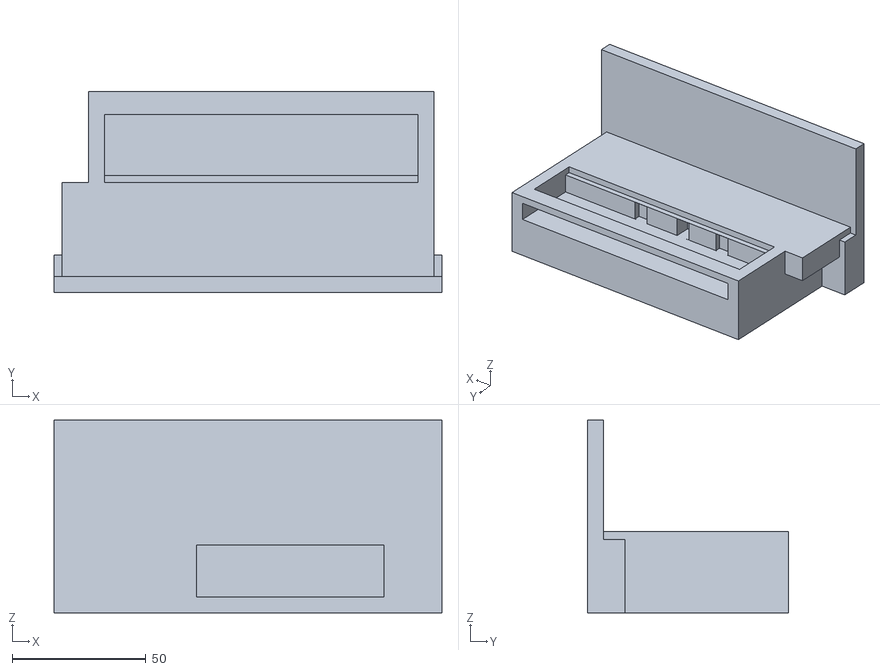
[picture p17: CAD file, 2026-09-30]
disenos/stl/freddos-fuengirola/opcion-tap/03_cuna_letras_negras.stl
144.8 x 75.0 x 72.0

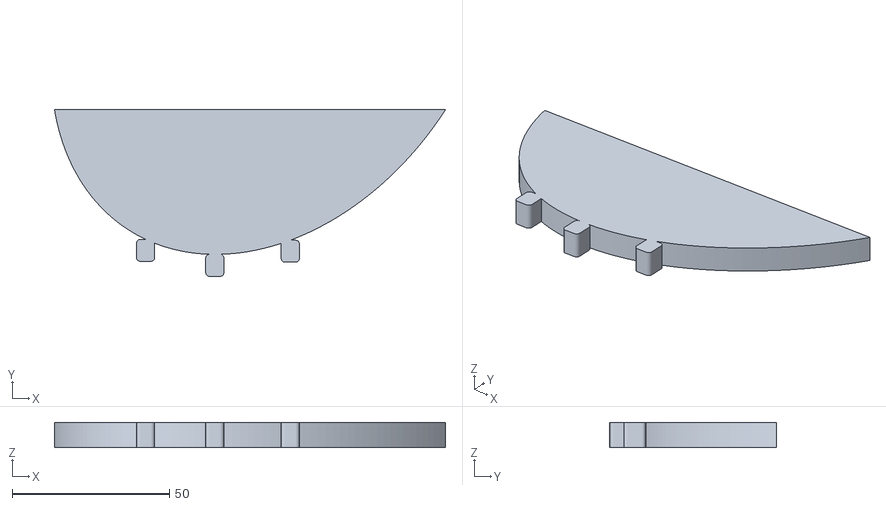
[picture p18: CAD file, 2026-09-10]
disenos/stl/freddos-fuengirola/test-encaje/01_stub_grano.stl
124.3 x 53.0 x 8.00

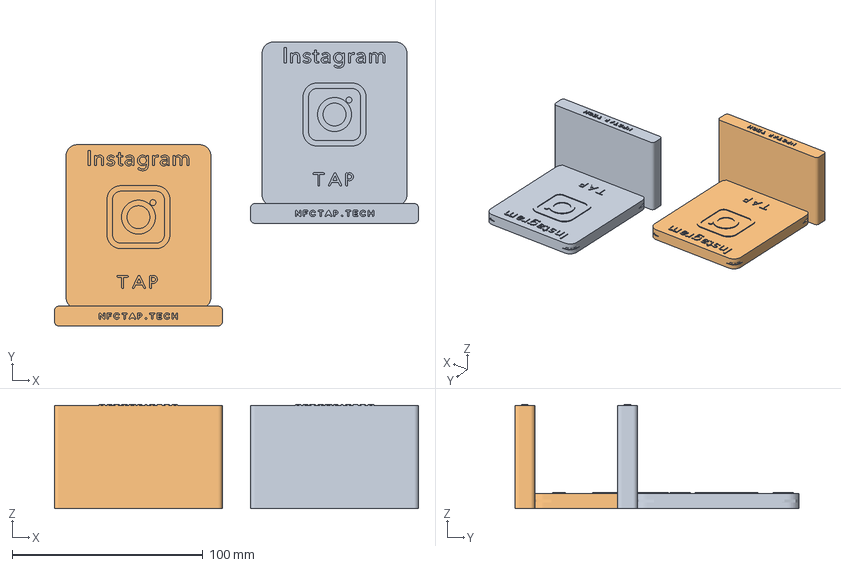
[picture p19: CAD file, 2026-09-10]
disenos/stl/generica-instagram-negra-amarillo/insta general.3mf
190.8 x 148.8 x 54.7 mm
01_cuerpo x 2

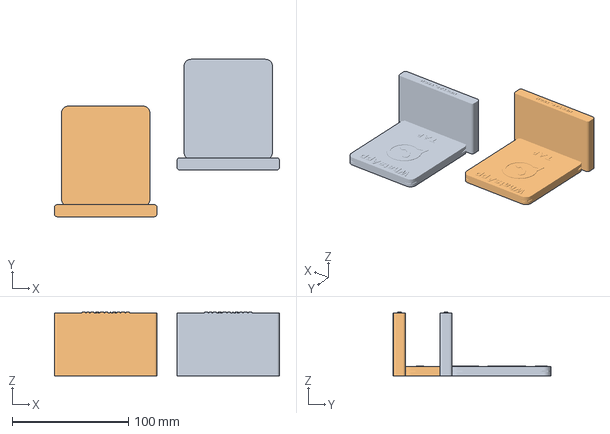
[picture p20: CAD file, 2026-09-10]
disenos/stl/generica-whatsapp-negra-amarillo/whatsapp generica.3mf
193.2 x 135.3 x 54.7 mm
01_cuerpo x 2

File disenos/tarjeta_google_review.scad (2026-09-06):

// Tarjeta NFC para reseñas de Google — Flashforge AD5X
// Abre en OpenSCAD (https://openscad.org) y pulsa F6 para exportar STL.
// Cambia los parámetros en el Customizer (panel izquierdo).

/* [Tarjeta] */
ancho = 86;          // mm  (tamaño tarjeta de crédito)
alto  = 54;
grosor = 3.6;
radio = 4;

/* [NFC] */
// Stock: Timeskey B08LD99GZT — pegatina PET NTAG215 Ø25 mm. Hueco holgado Ø28.4.
nfc_tipo = "moneda";   // [tira, moneda]
nfc_tira_w = 47;
nfc_tira_h = 17;
nfc_moneda_d = 28.4;
nfc_grosor = 0.8;
nfc_desde_base = 1.2;  // deja 6 capas de 0.2 mm debajo

/* [Pieza a generar] */
pieza = "cuerpo";    // [cuerpo, estrellas, texto, icono, soporte, ensamblado]

/* [Texto] */
linea1 = "TOCA PARA";
linea2 = "RESENA";

$fn = 48;

module tarjeta_redondeada(w, h, r, t) {
    linear_extrude(t)
        offset(r=r)
            square([w - 2*r, h - 2*r], center=true);
}

module hueco_nfc() {
    translate([0, 0, nfc_desde_base])
        if (nfc_tipo == "moneda")
            cylinder(h=nfc_grosor, d=nfc_moneda_d);
        else
            translate([0, 0, nfc_grosor/2])
                cube([nfc_tira_w, nfc_tira_h, nfc_grosor], center=true);
}

module cuerpo() {
    difference() {
        tarjeta_redondeada(ancho, alto, radio, grosor);
        hueco_nfc();
    }
}

module estrella(r=3.6) {
    points = [for (i = [0:9])
        let(a = i * 36 - 90, rr = i % 2 == 0 ? r : r * 0.42)
        [rr * cos(a), rr * sin(a)]
    ];
    linear_extrude(0.4) polygon(points);
}

module estrellas() {
    translate([0, 0, grosor])
        for (i = [-2:2])
            translate([i * 9, alto/2 - 10, 0])
                estrella();
}

module textos() {
    translate([6, 4.5, grosor])
        linear_extrude(0.4)
            text(linea1, size=5.5, font="Liberation Sans:style=Bold",
                 halign="center", valign="center");
    translate([6, -6.5, grosor])
        linear_extrude(0.4)
            text(linea2, size=7.5, font="Liberation Sans:style=Bold",
                 halign="center", valign="center");
}

module icono() {
    translate([-ancho/2 + 14, 0, grosor]) {
        difference() {
            cylinder(h=0.4, r=8.2);
            translate([0, 0, -0.1]) cylinder(h=0.6, r=6.6);
        }
        estrella(4.4);
    }
}

module soporte() {
    base_w = ancho + 8;
    base_d = 28;
    translate([0, 0, 0])
        linear_extrude(3)
            offset(r=3) square([base_w - 6, base_d - 6], center=true);
    translate([0, -base_d/2 + 8, 0])
        cube([base_w, 10, alto * 0.55], center=false);
}

if (pieza == "cuerpo")      cuerpo();
else if (pieza == "estrellas") estrellas();
else if (pieza == "texto")   textos();
else if (pieza == "icono")   icono();
else if (pieza == "soporte") soporte();
else {
    color("#222") cuerpo();
    color("#F4C430") estrellas();
    color("#FFF") textos();
    color("#FFF") icono();
}

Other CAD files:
disenos/stl/generica-negra-roja/01_cuerpo.stl
disenos/stl/generica-negra-amarillo/01_cuerpo_b.stl
disenos/stl/alberto-cartera/01_cuerpo.stl
disenos/stl/boton-nfctap/01_cuerpo.stl
disenos/stl/boton-nfctap/03_aro.stl
disenos/stl/freddos-fuengirola/01_grano_negro.stl
disenos/stl/freddos-fuengirola/02_grano_oro.stl
disenos/stl/freddos-fuengirola/03_cuna_letras_negras.stl
disenos/stl/freddos-fuengirola/fredos grano.3mf
disenos/stl/generica-blanca-negra/01_cuerpo.stl
disenos/stl/generica-blanca-negra/01_cuerpo_b.stl
disenos/stl/generica-blanca-negra/02_acento_a.stl
disenos/stl/generica-blanca-negra/02_acento_b.stl
disenos/stl/generica-instagram-negra-amarillo/01_cuerpo.stl
disenos/stl/generica-instagram-negra-amarillo/02_acento.stl
disenos/stl/generica-negra-amarillo/01_cuerpo.stl
disenos/stl/generica-negra-amarillo/02_acento_a.stl
disenos/stl/generica-negra-amarillo/02_acento_b.stl
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

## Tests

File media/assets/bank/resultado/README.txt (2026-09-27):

HOOK · pieza ACABADA (resultado final).

Carpeta:
  /Users/albertogarciaarroyo/impresora 3d/media/assets/bank/resultado/

Pega aquí MOV/MP4 de la pieza ya impresa: atril en mesa, TAP, genérica,
personalizada, dos piezas… Cualquier vídeo vale para empezar.

El sistema lo pone a 1080×1920. El nombre del archivo ayuda, no es obligatorio.

El pack evita los hooks ya usados: un vídeo nuevo aquí sale en el siguiente Reel.

En el mismo día, María y Andrés no empiezan con el mismo archivo.

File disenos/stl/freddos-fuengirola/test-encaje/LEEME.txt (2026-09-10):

Test de encaje Freddo's (30-40 min, SIN NFC)
===========================================
01_stub_grano + 02_cuna_nido. Negro los dos.
Cuna de pie. Stub de canto, tetones primero.
Prueba: encajar, tap con un móvil, tirar hacia arriba, empujar.
Si no sale ni baila, imprime la pieza buena (01-04).
Pega cinta 3M bajo el pie ANTES de juzgar el vuelco.

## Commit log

2026-09-05 Publicar NFCTab con editor 3D vertical y CI en cada push.
    La tienda y el personalizador quedan en el repo para que Actions valide lint y build al subir cambios.
    [01_cuerpo.stl, 02_estrellas.stl, 03_texto.stl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]
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2026-09-06 Ajustar el hueco NFC a las pegatinas Timeskey Ø25 mm.
    Todas las plantillas y el ZIP de impresión usan moneda_25 con holgura (~Ø28,4 mm) para meter el chip en la pausa sin que roce.
    [01_cuerpo.stl, tarjeta_google_review.scad]
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2026-09-06 Subir el build de iOS a 2 para poder publicar el arreglo en TestFlight.
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2026-09-06 Añadir la tarjeta de cartera slim con dos NFC y relieve oro NFCTap.
    Es la primera pieza de Alberto: negro + oro, huecos internos y pausa en capa 10 para las pegatinas Timeskey.
    [01_cuerpo.stl, 02_oro.stl]
2026-09-07 Dejar la cartera en un 3MF de Flash Studio y quitar restos que no se usan.
    El archivo único a abrir es alberto-cartera.3mf (cuerpo y oro ya montados). Se eliminan el package.json suelto de la raíz y el flujo de importar STL a mano.
    [alberto-cartera.3mf]
2026-09-07 Sustituir el 3MF roto por STL de cartera que Flash Studio puede abrir.
    El 3MF lo cargaba como geometría antigua y unía las piezas en una malla no-manifold. El oro lleva ancla en la cama para que las letras no caigan al suelo.
    [01_cuerpo.stl, 02_oro.stl, alberto-cartera.3mf]
2026-09-07 Usar Agrupar en Flash Studio y restaurar el cuerpo de la cartera.
    En Mac no aparece Ensamblar; Agrupar junta cuerpo y oro. El aviso de colisión es normal hasta agrupar.
    [01_cuerpo.stl]
2026-09-07 Subir la firma de la cartera y no reparar el modelo en Flash Studio.
    Reparar partía el cuerpo en 1,2 mm. La firma queda más dentro del borde para la primera impresión.
    [02_oro.stl]
2026-09-07 Poner TAP / RESEÑA (con ñ) en el atril de 15 € y poder imprimir dos en la cama.
    [01_cuerpo.stl, 01_cuerpo_x2.stl, 01_grano_negro.3mf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]
2026-09-08 Dejar la G oficial de Google en la genérica y el mismo atril con logo en acento.
    [01_cuerpo_a.stl, 01_cuerpo_b.stl, 01_cuerpo_x2.stl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]
2026-09-08 Dejar el hueco NFC abierto y que la web imprima el mismo atril que Flash.
    Así la pegatina no queda tapada (no montañitas) y el cliente ve en la web exactamente el cuerpo y acento que luego abre en el slicer.
    [01_cuerpo.stl, 01_cuerpo_a.stl, 01_cuerpo_b.stl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]
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2026-09-08 Quitar el cuadradito de ancla y bajar el diseño para igualar web y Flash.
    Era un cubo de alineación en el acento: salía en el visor y en el slicer. El bloque de estrellas y G deja aire arriba, el mismo en ambos.
    [01_cuerpo.stl, 01_cuerpo_a.stl, 01_cuerpo_b.stl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]
2026-09-08 Repartir estrellas, G y TAP como en Flash: G grande y hueco abajo.
    Así la web y el STL coinciden: no va todo pegado arriba. En personalizada el logo ocupa exactamente el sitio de la G.
    [01_cuerpo.stl, 01_cuerpo_a.stl, 01_cuerpo_b.stl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]
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2026-09-08 Bajar G y TAP con más aire, dejar la pieza única en texto y cobrar envío en 24 h.
    [02_acento.stl, 02_acento_a.stl, 02_acento_b.stl]
2026-09-08 Quitar el círculo inventado del visor y dejar G y TAP como en la pieza impresa.
    [02_acento.stl, 02_acento_a.stl, 02_acento_b.stl]
2026-09-08 Ocultar el hueco NFC en la tienda y dejar G y TAP con la holgura de Flash.
    [02_acento.stl, 02_acento_a.stl, 02_acento_b.stl]
2026-09-08 Bajar G, logo y TAP a la misma altura que la pieza de Flash, estrellas arriba.
    [02_acento.stl, 02_acento_a.stl, 02_acento_b.stl]
2026-09-08 Letras TAP sans con más tracking, cuatro caras para elegir y dashboard de reseña Google.
    El pozo NFC sigue bajo la G con pausa (sin montañita). Genéricas y personalizadas usan la misma tipografía; las opciones están en negro+dorado.
    [01_cuerpo.stl, 01_cuerpo_a.stl, 01_cuerpo_b.stl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]
2026-09-08 Fijar la genérica flotante: TAP redondeado bajo la G y sin caras extra.
    Las letras TAP y NFCTAP.TECH van en cápsula para que no se vean robóticas al imprimir, y TAP baja para quitar el hueco feo sobre la base.
    [01_cuerpo.stl, 02_acento.stl, 02_acento_a.stl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]
2026-09-10 Dejar Freddo's con el wordmark entero y el grano encajado, y sumar las genéricas Instagram y WhatsApp.
    El nido ya no corta las letras: va detrás/arriba, con prueba de solape y tetones. STL, test de encaje y propuesta montada van juntos.
    [01_cuerpo.stl, 01_cuerpo_a.stl, 01_cuerpo_b.stl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]
2026-09-10 Asegurar el encaje de Freddo's: wordmark libre y grano que cae sin rozar.
    El pie ya no tapa las letras, la ranura queda a 0,4 mm y las pruebas de solape e inserción tienen que pasar antes de exportar STL.
    [02_cuna_nido.stl, 03_cuna_letras_negras.stl, 04_letras_oro.stl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]
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2026-09-20 Vender el TAP Wi‑Fi de pared a 15 €, con visor 3D y Polar.
    El atril sigue siendo lo principal; esta placa fija (adhesivo incluido) se recomienda al encargar y se cobra en el mismo pedido o suelta.
    [01_cuerpo.stl, 02_acento.stl]
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2026-09-27 Arreglar la activación de la lista: misma clave por defecto que el dashboard.
    En producción rechazaba nfctab aunque el dashboard la aceptaba; ahora coincide y se muestra el error si falla.
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2026-09-27 Arreglar la persistencia de la lista: leer el Blob privado con get().
    Sin eso, al recargar parecía vacía aunque se hubiera guardado. No usa Neon ni SQL.
2026-09-27 Fix: la lista de la compra dejaba de abrir (500 al guardar cookie).
    Next no permite Set-Cookie en el render de la página; la activación pasa por la API y los ítems en Blob no se tocan.
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2026-09-29 Fix lint panel: quitar setState en effect y usar Link de Next.
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2026-10-28 Arreglar lint de checkout en /negocio y añadir PDF de otros servicios.
    Redirect con location.assign; packs de redes y piezas a medida en /otros-servicios.pdf.
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2026-10-29 Anclar el logo del cliente al círculo real del modelo 3D.
    Corrige la posición del disco (antes flotaba) y tapa el sello Markos.
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2026-10-29 Discover fail-fast: 2 mirrors Overpass y menos ciudades por tick.
    Evita que el cron se quede colgado sin respuesta al rellenar cola.
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2026-10-29 Fix webhook Resend: dejar de devolver 401 cuando el secret Svix está en Vercel.
    Sin esto el panel de captación se queda en 0 abiertos aunque Resend Metrics sí cuente opens.
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2026-11-01 Fix cron UTC para 10 oleadas Madrid (invierno y verano).
    El horario 8–17 UTC dejaba fuera la oleada de las 8:00 y el tick de las 18:00 se saltaba → máximo ~450/día.
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2026-11-01 Dashboard captación: pipeline FU A/B/C y cupos cold/FU del día.
    Corrige el conteo del día de migración (enviados previos = cold) para no pasarnos del cupo.
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2026-11-01 Fix FU atascados: sincronizar bajas con la cola y mantener harvest vivo.
    Los «due» del panel eran clicks en opt-out sin cerrar secuencia; el envío los saltaba y solo mandaba cold.
